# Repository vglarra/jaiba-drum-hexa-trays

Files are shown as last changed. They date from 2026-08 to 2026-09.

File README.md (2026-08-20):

# Jaiba Drum — Hex Trays

Blender Python scripts that generate the flat hexagonal sensor plates for the Jaiba electronic hand drum, split into printable left/right halves. Two versions are included: a stable base plate, and a newer version that adds a containment wall around the tray. If the wall version gives you trouble, the base plate is the one to fall back on — it's the simpler, proven calculation everything else builds on.

## What's in this repo

| File | Description |
|---|---|
| `jaiva-hexa-drum-trays-script.py` | **Base plate script.** Generates the flat hex tile plate (left + right halves) with wire holes and connector pin holes. This is the core geometry — start here. |
| `jaiva-hexa-drum-trays-walls-script.py` | **Tray + wall script.** Same base plate, plus a containment wall traced around the true outer boundary of each half (for holding cast silicone sensor cups in place). Newer and less battle-tested than the base script. |
| `flat_hex_plate_LEFT.stl` / `flat_hex_plate_RIGHT.stl` | Exported STLs from the base plate script. |
| `flat_hex_plate-Walls_LEFT.stl` / `flat_hex_plate-Walls_RIGHT.stl` | Exported STLs from the tray + wall script. |
| `jaiba-drum-hexa-trays-1.blend` | Blender project file for the base plate. |
| `jaiba-drum-hexa-tray-walls-2.blend` | Blender project file for the tray + wall version. |

## Geometry overview

- **16 hex tiles total**, split into a 7-tile left half and a 9-tile right half (split point picked automatically at the widest natural gap in the tile grid, so the cut falls in a sensible spot rather than through a tile).
- Each tile is **84mm flat-to-flat**, with a 3mm perimeter ridge built only on tiles' true exterior edges (interior tile-to-tile boundaries are left flat).
- Each tile has a **12mm wire hole** on its own face, and (base script only) a **15mm connector pin hole** on tiles that pair up across the seam between neighboring tiles.
- The two halves are pushed apart by a configurable gap (`INVISIBLE_TILE_GAP`) so they don't overlap once split.
- The wall version adds a **6mm-wide, 26mm-tall** wall traced along the *real* outer boundary of each half — not a bounding box or convex hull, since the tile array is a non-convex "flower" shape and either of those would cut across the concave notches between lobes.

## Requirements

- Blender 4.x (uses `bpy`, `bmesh`, and the `wm.stl_export` operator)
- No external Python packages — everything is built from Blender's own modules

## Usage

1. Open Blender's **Scripting** workspace.
2. Load either script (`jaiva-hexa-drum-trays-script.py` for the base plate, or `jaiva-hexa-drum-trays-walls-script.py` for the version with the wall).
3. Adjust the parameters at the top of the file if needed (tile size, hole diameters, wall dimensions, etc. — see the script's own printed summary at the top of the console output for a full readout of the computed geometry).
4. Run the script. It builds both halves, prints a manifold-cleanliness report for each (non-manifold edge / zero-area face counts — should be at or near zero), and exports STLs next to the `.blend` file.

## Status

- **Base plate script** — stable. Tile geometry, wire holes, and pin holes are the proven calculation the rest of this project is built on.
- **Tray + wall script** — actively being refined. The wall-tracing logic has gone through several iterations to correctly follow the array's concave boundary and close every corner/end cleanly; check the console's manifold report after each run before trusting the exported STL.

## Background

Part of the Jaiba hexagonal electronic drum project — each hex tile hosts a silicone-isolated piezo/Velostat sensor cup, cast using a separate mold-core system, intended to reduce vibration cross-talk between adjacent pads.

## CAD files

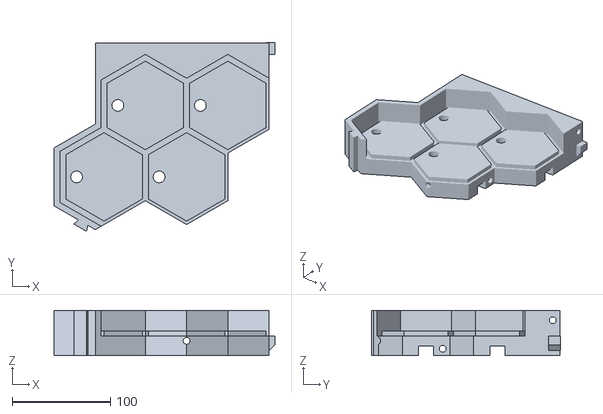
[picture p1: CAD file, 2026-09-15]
flat_hex_plate-Walls2_TOP_LEFT.stl
225.0 x 192.3 x 46.0

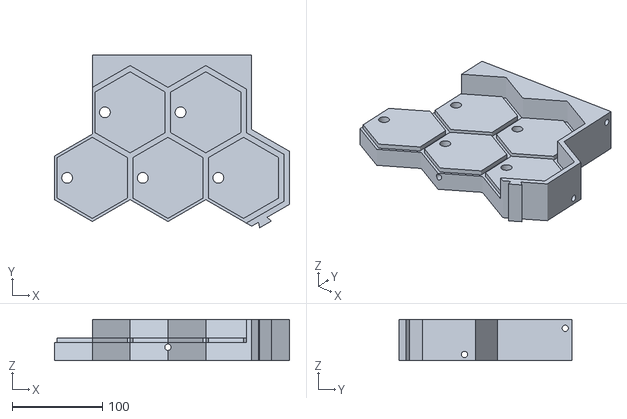
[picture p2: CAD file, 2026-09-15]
flat_hex_plate-Walls2_TOP_RIGHT.stl
261.0 x 191.8 x 46.0

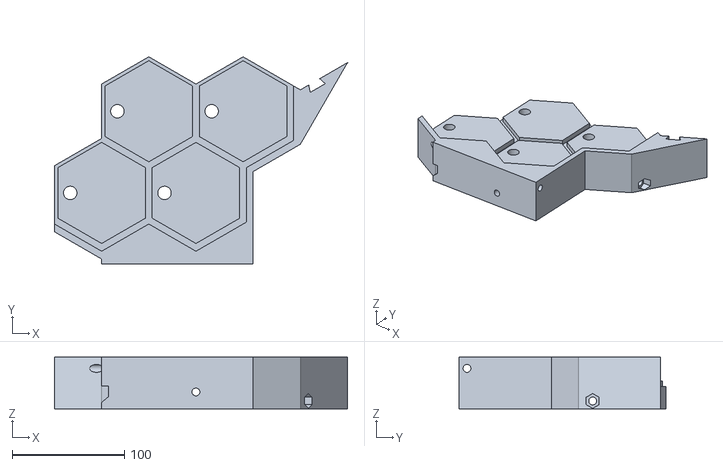
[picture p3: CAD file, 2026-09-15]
flat_hex_plate-Walls2_BOTTOM_RIGHT.stl
261.0 x 184.7 x 46.0

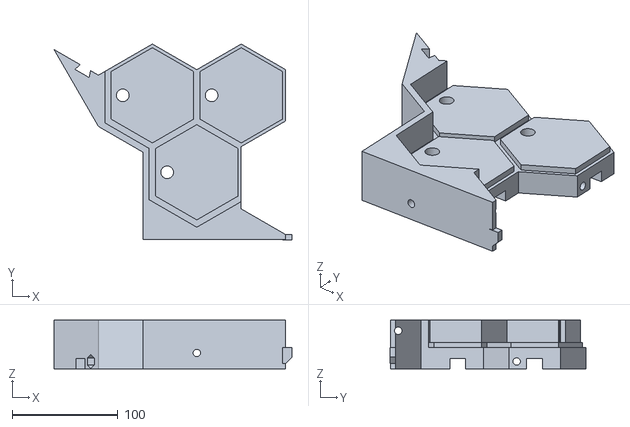
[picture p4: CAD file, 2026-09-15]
flat_hex_plate-Walls2_BOTTOM_LEFT.stl
225.0 x 185.2 x 46.0

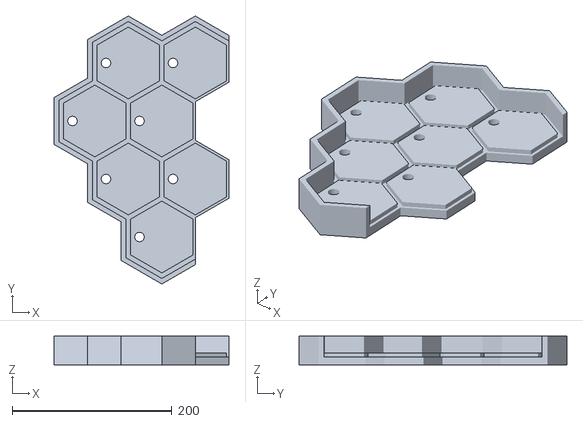
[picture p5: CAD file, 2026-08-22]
flat_hex_plate-Walls2_LEFT.stl
219.0 x 336.0 x 36.0

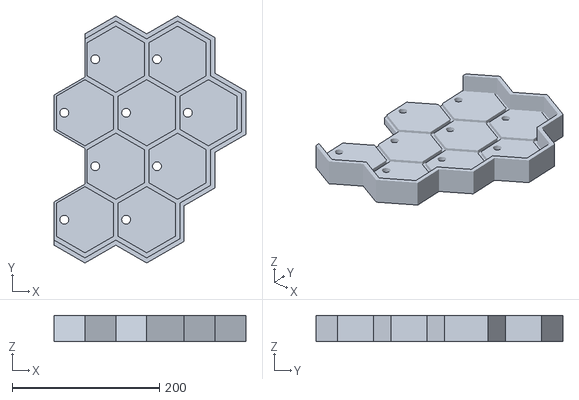
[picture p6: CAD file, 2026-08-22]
flat_hex_plate-Walls2_RIGHT.stl
261.0 x 336.0 x 36.0

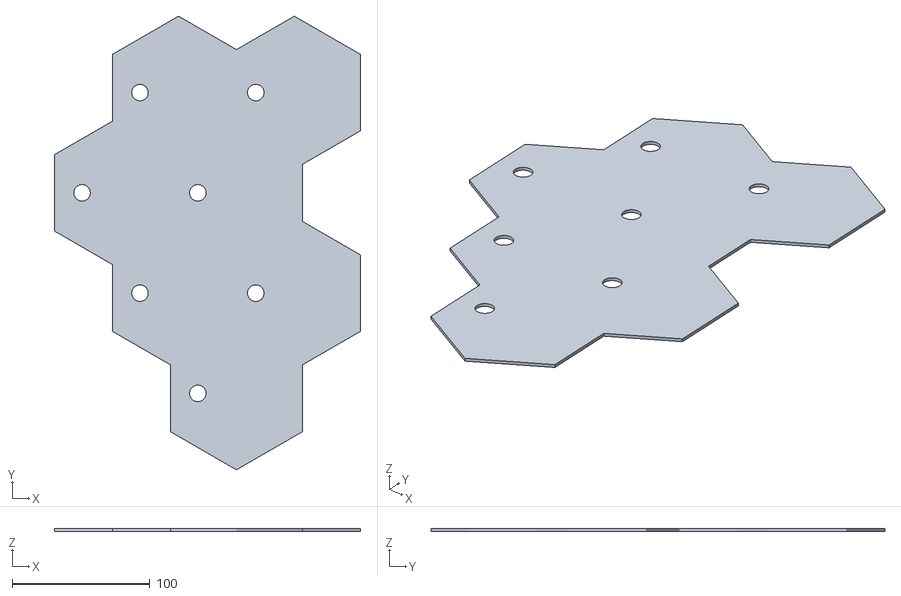
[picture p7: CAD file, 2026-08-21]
flat_hex_plate_LEFT.stl
222.0 x 329.1 x 2.00

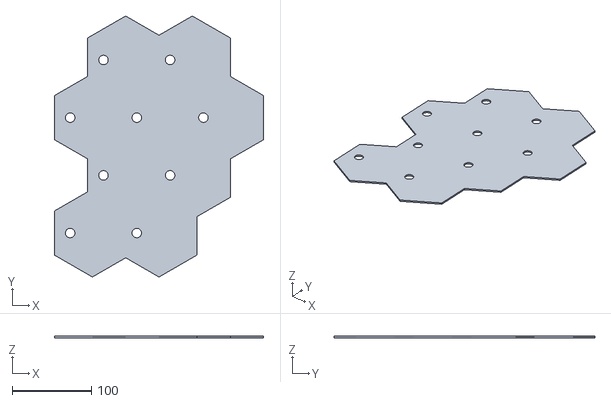
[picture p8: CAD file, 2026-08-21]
flat_hex_plate_RIGHT.stl
264.0 x 329.1 x 2.00

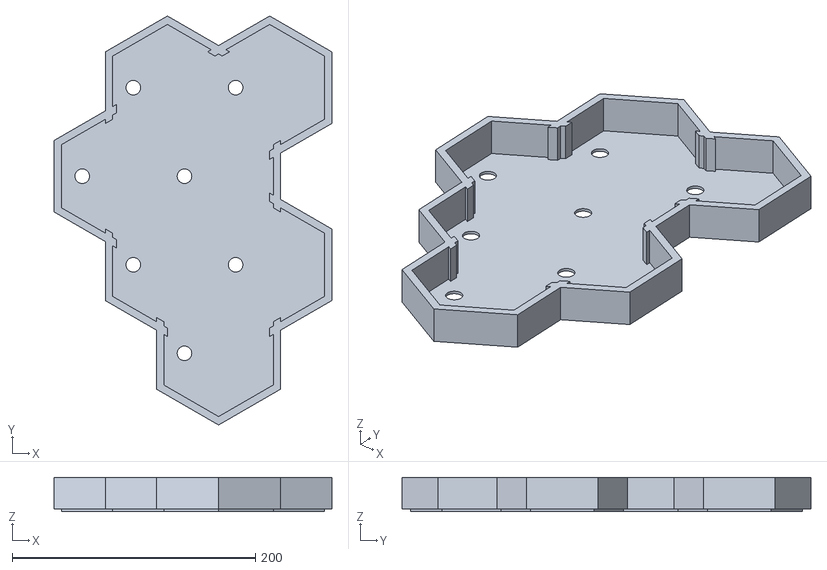
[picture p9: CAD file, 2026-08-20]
flat_hex_plate-Walls_LEFT.stl
228.0 x 336.0 x 28.0

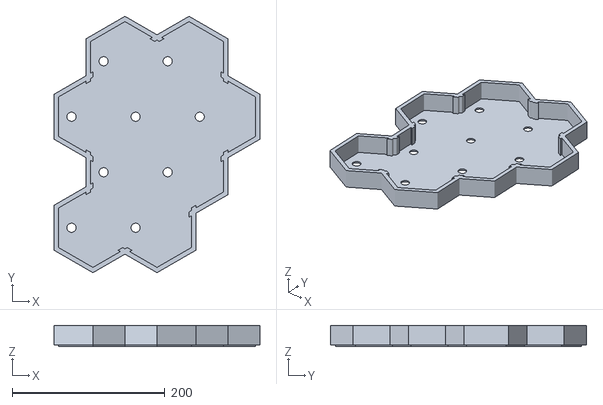
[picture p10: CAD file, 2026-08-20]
flat_hex_plate-Walls_RIGHT.stl
270.0 x 336.0 x 28.0

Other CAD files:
jaiba-drum-hexa-tray-walls-2.blend
jaiba-drum-hexa-trays-1.blend

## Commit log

2026-08-20 Initial commit: hexa drum tray scripts, Blender sessions, and STL exports
    Add Python generator scripts for the tray and wall geometry, their
    Blender source files, and the exported flat hex plate STLs. Ignore
    .blend1 autosave backups.
    [flat_hex_plate-Walls_LEFT.stl, flat_hex_plate-Walls_RIGHT.stl, flat_hex_plate_LEFT.stl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]
2026-08-21 Add hex tray wall+perimeter script with gap-aware contour matching
    New script builds the full plate body (flat hex tiles, 3mm perimeter,
    6mm/26mm wall) via direct bmesh construction, computing each boundary
    offset once per shared vertex instead of per tile so neighboring tiles'
    walls always join flush. Edges facing the invisible-tile gap between the
    Left/Right plates get a plain flat closing wall instead of the
    perimeter/wall bulge, so the two plates' contours still read as one
    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
    [flat_hex_plate-Walls2_LEFT.stl, flat_hex_plate-Walls2_RIGHT.stl, flat_hex_plate_LEFT.stl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]
2026-08-21 Add inner sensor platform and fix wire-hole boolean corruption
    Add a raised 78mm hex platform (5mm tall) on top of each base tile,
    same center, with a 6mm gap between neighbors for the vibration-damping
    textile strip. Change the tile top face from a solid 84mm hex to a ring
    (84mm to 78mm) instead, since a solid top coincided exactly with the
    platform's own bottom face at the same Z height -- that overlap was
    corrupting wire-hole boolean cuts (a tile could lose its whole top
    surface without any error). Add a boolean-leak check that catches a
    cut reporting success without actually removing material, and force a
    mesh/viewport refresh after building each plate.
    [flat_hex_plate-Walls2_LEFT.stl, flat_hex_plate-Walls2_RIGHT.stl]
2026-08-22 Add JOIN_PLATES switch to fit LEFT/RIGHT plates flush together
    Setting JOIN_PLATES = True zeroes GAP_BETWEEN_PLATES so the RIGHT
    plate's grid sits flush against the LEFT plate's split edge instead
    of the default INVISIBLE_TILE_GAP spacing.
    [flat_hex_plate-Walls2_RIGHT.stl, jaiba-drum-hexa-tray-walls-2.blend]
2026-08-22 Fix mismatched wall miter at the split seam between plates
    Each half's boundary offset map only ever saw one of the two true-
    exterior wall edges meeting at a split-line vertex (the other tile
    lives in the other plate's mesh), so it fell back to a single-edge
    normal instead of a proper miter -- LEFT and RIGHT independently
    computed different offsets for what should be the same point,
    producing a mismatched notch where the walls meet once joined.
    Now compute the offset map once over the full, unsplit 16-tile grid
    and have each half override its local offsets with the globally-
    mitered values, so both plates agree on identical wall-corner points
    along the split line.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
    [flat_hex_plate-Walls2_LEFT.stl, flat_hex_plate-Walls2_RIGHT.stl]
2026-08-22 Add row split for 4-way quarter-plate printing
    Splits the grid a second time along Y (between the two middle rows,
    with a 3mm-per-side margin) in addition to the existing X split,
    producing four quadrant plates (TL/TR/BL/BR) instead of two halves.
    Tile labels (L00.., R00..) are preserved from the original L/R split
    so a tile keeps the same tag regardless of which quadrant it ends up
    in. The boundary-offset "globalize" fix from the previous commit now
    threads shift_y as well as shift_x, so wall miters stay consistent
    across both split axes, including the diagonal seams where a tile's
    neighbor lands in the opposite quadrant.
    Exports flat_hex_plate-Walls2_{TOP,BOTTOM}_{LEFT,RIGHT}.stl in place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
    [flat_hex_plate-Walls2_BOTTOM_LEFT.stl, flat_hex_plate-Walls2_BOTTOM_RIGHT.stl, flat_hex_plate-Walls2_LEFT.stl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]
2026-08-22 Thicken base plate to 20mm and add X-axis threaded-rod holes
    PLATE_H 2.0 -> 20.0mm so threaded rods can be driven through the base
    slab to clamp the 4 quadrant plates together. Adds two horizontal
    7mm rod holes along X, one per row straddling the row-split boundary
    (X_L02-R04 through TL/TR, X_L04-R06 through BL/BR), offset in Y to
    clear the vertical wire holes (which run the full part height, so Z
    can't be used to dodge them).
    X_L04-R06 is offset -20mm (moved 35mm further towards Y- from the
    other hole's +15mm), putting it on the opposite side of the row
    centerline from the wire holes for more clearance there.
    [flat_hex_plate-Walls2_BOTTOM_LEFT.stl, flat_hex_plate-Walls2_BOTTOM_RIGHT.stl, flat_hex_plate-Walls2_TOP_LEFT.stl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]
2026-08-22 Add Y-axis threaded-rod holes and split rod Z-heights to avoid collision
    Adds two vertical-column rod holes (Y_L00-L01_L06 and Y_R00-R01_R08)
    at X = +-HEX_FLAT_WIDTH (+ GAP_BETWEEN_PLATES on the right), uniting
    TL/BL and TR/BR the same way the existing X-axis holes unite TL/TR
    and BL/BR -- so all 4 quadrants are now cross-braced on both axes.
    Since some X-axis and Y-axis rods physically cross the same point
    (e.g. X_L02-R04 passes straight through L03, which sits exactly on
    the Y_L00-L01_L06 column), moved them off the shared PLATE_H/2 center
    onto the two quarter-points of PLATE_H (5mm and 15mm) so their Z
    ranges don't overlap -- 10mm apart, an even division of the 20mm slab.
    Co-Authored-By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
    [flat_hex_plate-Walls2_BOTTOM_LEFT.stl, flat_hex_plate-Walls2_BOTTOM_RIGHT.stl, flat_hex_plate-Walls2_TOP_LEFT.stl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]
2026-08-22 Add wire-routing canals, fix bottom-face boolean cut, tune rod clearance
    Adds 4 wire-routing canals (Canal_L00-R01/L02-R04/L04-R06/L06-R08), one
    per row, connecting every wire hole on that row through a 15mm-wide,
    10mm-deep pocket cut up from the bottom face. Each canal starts at its
    row's rightmost hole and runs left through the leftmost hole and out
    through the left outer wall, so all 4 meet on the L00-L06 side.
    The canal cutter's bottom face was initially placed exactly at Z=0,
    coplanar with the target mesh's own bottom face -- a degenerate case
    for the boolean solver that left a thin uncut skin there (canal only
    visible in cross-section, not as a real opening from below). Fixed by
    start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
    [flat_hex_plate-Walls2_BOTTOM_LEFT.stl, flat_hex_plate-Walls2_BOTTOM_RIGHT.stl, flat_hex_plate-Walls2_TOP_LEFT.stl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]
2026-08-22 Rework top/bottom reinforcement as rails, fix length and Y placement
    Reworks the earlier reinforcement-rib attempt into simpler
    top/bottom "rails": a 25mm-from-tip union'd box per row half plus a
    7mm rod hole, built as the last step so it runs against otherwise
    unchanged geometry. JOIN_PLATES now defaults on.
    Two fixes on top of that:
    - Rail length now reaches the wall's actual mitered outer surface
    (via GLOBAL_WALL_OFFSET, the same offset the wall itself is built
    from) instead of stopping at the raw hex corner, so the rail's ends
    sit flush with the wall instead of leaving it sticking out past the
    rail edge.
    - Fixed a tuple-unpack bug that assigned BOTTOM_TIP_Y from the wrong
    elem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
    [flat_hex_plate-Walls2_BOTTOM_LEFT.stl, flat_hex_plate-Walls2_BOTTOM_RIGHT.stl, flat_hex_plate-Walls2_TOP_LEFT.stl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]
2026-08-22 Reduce rail depth to 15mm and move rail rods near tip-side wall seam
    Shrinks RAIL_TOTAL_FROM_TIP from 25mm to 15mm, narrowing the rail box
    to 8mm deep, and moves RAIL_ROD_OFFSET_FROM_OUTER to 4.3mm so the rod
    sits close to the inner (tip+7) face where the rail meets the
    existing wall, with a small safety margin on both faces.
    [flat_hex_plate-Walls2_BOTTOM_LEFT.stl, flat_hex_plate-Walls2_BOTTOM_RIGHT.stl, flat_hex_plate-Walls2_TOP_LEFT.stl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]
2026-08-22 Fix non-manifold rail/wall geometry: remove spurious platform cap, make rail merge ownership-aware
    Two real bugs found and fixed, confirmed by replicating the mesh
    construction in plain Python and directly counting face-per-edge
    adjacency instead of guessing from Blender's boolean solver logs:
    1. build_plate_body built a spurious cap face at each sensor
    platform's own underside (ibot). The platform sits on solid
    material, not floating, so that boundary needs zero faces there --
    building one created a 3-faces-per-edge non-manifold ring around
    every platform, in every quadrant, since the very first build this
    session (exactly explains every quadrant's baseline non-manifold
    c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
    [flat_hex_plate-Walls2_BOTTOM_LEFT.stl, flat_hex_plate-Walls2_BOTTOM_RIGHT.stl, flat_hex_plate-Walls2_TOP_LEFT.stl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]
2026-08-22 Fix rail-merge face matching and Y-axis rod holes through rails
    - Replace exact-corner-subset face deletion in merge_rail_into_wall
    with a line/span/Z containment test: earlier rod-hole cuts could
    split a wall-outer face into fragments that no longer had all 4
    original corners, so the old matcher silently left them behind
    (e.g. BottomRail_L's "0 obsolete faces replaced").
    - Consolidate the Y-axis threaded-rod holes into a single cut that
    runs after the rails are merged in, instead of cutting once before
    the rails exist and again as an "extension" afterward -- the second
    cut's cylinder was exactly coincident with the first cut's own
    tunnel-wall surface, which the EXACT solver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
    [flat_hex_plate-Walls2_BOTTOM_LEFT.stl, flat_hex_plate-Walls2_BOTTOM_RIGHT.stl, flat_hex_plate-Walls2_TOP_LEFT.stl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]
2026-08-22 Move rail rods 3mm further inward from the outer boundary
    Increases RAIL_ROD_OFFSET_FROM_OUTER from 4.3mm to 7.3mm (Z and X
    unchanged), giving the rod more clearance from the rail's outer edge.
    Landed at 7.3 after 8.3 (a full 4mm move) put the rod close enough to
    a peak's tip that the hex wedge there was barely wider than the rod
    itself, cutting through the tip's side walls.
    [flat_hex_plate-Walls2_BOTTOM_LEFT.stl, flat_hex_plate-Walls2_BOTTOM_RIGHT.stl, flat_hex_plate-Walls2_TOP_LEFT.stl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]
2026-08-23 Move X-axis rod holes up to clear the Y-axis rods by 1mm
    ROD_HOLE_Z_X_AXIS was PLATE_H/4 (5.0mm), only 1.5mm clear of Z=0 and
    close enough to the Y-axis rods (Z=15.0) to invite trouble. The two
    rod centerlines are perpendicular horizontal skew lines, so their
    minimum separation is always exactly the Z gap between them regardless
    of X/Y offset; they go tangent at ROD_HOLE_Z_Y_AXIS - ROD_HOLE_DIAMETER
    (8.0mm). Set ROD_HOLE_Z_X_AXIS to 1mm below that tangent point (7.0mm),
    giving a real 1mm surface gap to the Y-axis rods and 3.5mm clearance
    from Z=0 instead of 1.5mm. Rail rod positions untouched.
    [flat_hex_plate-Walls2_BOTTOM_LEFT.stl, flat_hex_plate-Walls2_BOTTOM_RIGHT.stl, flat_hex_plate-Walls2_TOP_LEFT.stl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]
2026-08-26 Fix fit-tab female slot: inward-normal cutter bug and rectangular vs ramped shape
    The slot cut on SensorBase_TR/BR failed silently (boolean reported 2
    leaked cutter vertices, safe_cut refused to modify the mesh) because
    _extrude_profile_along_y built every prism cutter with inward-facing
    normals -- unions tolerated it, DIFFERENCE didn't. Fixed the winding
    at the source, which also incidentally fixed the pre-existing TR/BR
    canal-cut failures using the same code path. Also tightened
    try_cut_on_copy's corruption check, which was treating a cutter
    corner landing on the new cavity's own corner (expected, not
    corruption) as leaked/broken.
    Replaced the female slot's plain rectangular box cutter wi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
    [flat_hex_plate-Walls2_BOTTOM_LEFT.stl, flat_hex_plate-Walls2_BOTTOM_RIGHT.stl, flat_hex_plate-Walls2_TOP_LEFT.stl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]
2026-08-27 Nudge quadrants together in-scene for an assembled preview
    Object-position-only move (top row down 3mm, bottom row up 3mm) to
    close the 6mm row gap so all four printed quadrants sit flush for a
    visual check. Mesh data, export script, and STLs are unchanged -- the
    gap is still baked into the geometry for print separation.
    [jaiba-drum-hexa-tray-walls-2.blend]
2026-08-27 Auto-position quadrants into an assembled view after export
    Adds a script step, right after STL export, that nudges the four
    quadrant objects' own world-space location to close the
    ROW_SPLIT_MARGIN gap -- viewport-only, so the exported STLs keep the
    real print-separation gap in their geometry. Previously this had to be
    redone by hand after every script re-run since rebuilding the objects
    resets them to the origin.
2026-08-28 Label true-exterior wall segments (W1, W2, ...) for reference
    Walks the global boundary trace once, merging collinear plain-wall
    runs and rail-covered runs (by ownership, since the built rail face is
    flat even where the underlying tile edges zigzag) into one label each,
    plus a label at each rail's own end-cap transition back to the plain
    wall. Viewport-only text labels; no geometry is touched.
2026-08-29 Add W3 nut trap and fix W2/W3 corner wedge boolean issues
    Merges the W2/W3 corner-fill wedge into one seamless solid (deletes
    the now-buried old W3 wall face that was causing boolean corruption
    on any cutter crossing that region), extends the X_L04-R06 rod hole
    to reach the wedge's new outer surface, and adds a hex-shaped nut trap
    pocket (11.5mm across flats, 5.5mm deep) sized to the actual hardware
    (11.5mm hex nut, 17mm washer, 7mm rod) so the nut can't spin when the
    rod is tightened. The pocket's outer margin accounts for the wedge's
    slanted outer face to avoid leaving uncut material at its mouth.
    [flat_hex_plate-Walls2_BOTTOM_LEFT.stl, flat_hex_plate-Walls2_BOTTOM_RIGHT.stl, flat_hex_plate-Walls2_TOP_LEFT.stl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]
2026-09-08 Add W2/W3 vertical fit boss/socket and tune clearance to close visible seam gap
    Adds a tapered vertical boss on W2 (SensorBase_TL) that unions into a
    matching socket cut into the W2/W3 corner wedge on W3 (SensorBase_BL),
    registering the two prints against each other at that seam. Socket
    mouth margin, root overlap, and extra depth were tuned down (ruler-
    measured in Blender) to close a visible gap at the boss/socket mouth
    without introducing interference.
    [flat_hex_plate-Walls2_BOTTOM_LEFT.stl, flat_hex_plate-Walls2_TOP_LEFT.stl, jaiba-drum-hexa-tray-walls-2.blend]
2026-09-08 Shift W2/W3 fit boss/socket 10mm east toward corner C
    Adds FIT_U_OFFSET, applied to both the TL boss and BL socket frame
    origins identically so they stay aligned with each other. An earlier
    attempt moved the feature west toward A2 but landed on the wrong side
    visually and was rolled back; this moves it east instead.
    [flat_hex_plate-Walls2_BOTTOM_LEFT.stl, flat_hex_plate-Walls2_TOP_LEFT.stl]
2026-09-09 Replicate W2/W3 fit boss/socket at the mirrored east seam (W10/W11)
    Refactors the corner-fill wedge, nut-trap, and boss/socket logic into
    parameterized functions (merge_corner_fill, build_nut_trap,
    build_fit_boss_socket) shared by both seams instead of duplicating
    ~150 lines of hand-tuned boolean logic. The west call reproduces the
    original geometry bit-for-bit (verified via mesh_volume comparison on
    TL/BL before and after).
    Also fixes a real bug found in the process: _fit_wall_frame's normal
    formula used a fixed -90deg rotation of the tangent, which only picks
    the true outward direction for one winding chirality. The east seam's
    corner points are a mirror reflection of the west's, reversin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
    [flat_hex_plate-Walls2_BOTTOM_RIGHT.stl, flat_hex_plate-Walls2_TOP_RIGHT.stl, jaiba-drum-hexa-tray-walls-2.blend]
2026-09-15 Add rear-side hex lightening pockets, one per tile across all 16 tiles
    Cuts a hex prism pocket (50mm flat-width, Z=0..18mm) centered on each
    tile, aligned to the same hex-corner convention as the tile grid itself.
    Run before the corner/rail/boss geometry so those cuts land on uniform
    walls, same as the existing wire holes.
    [flat_hex_plate-Walls2_BOTTOM_LEFT.stl, flat_hex_plate-Walls2_BOTTOM_RIGHT.stl, flat_hex_plate-Walls2_TOP_LEFT.stl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]
